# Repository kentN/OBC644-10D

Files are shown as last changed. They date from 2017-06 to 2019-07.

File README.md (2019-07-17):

# OBC644-10D
ATmega644/1284-based arduino compatible on-board computer Reference Model

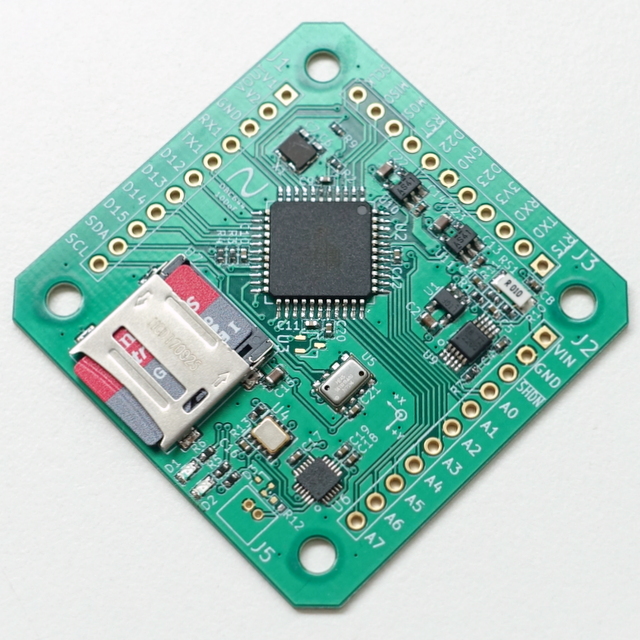
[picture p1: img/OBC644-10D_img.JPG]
PCB_img OBC644-10D

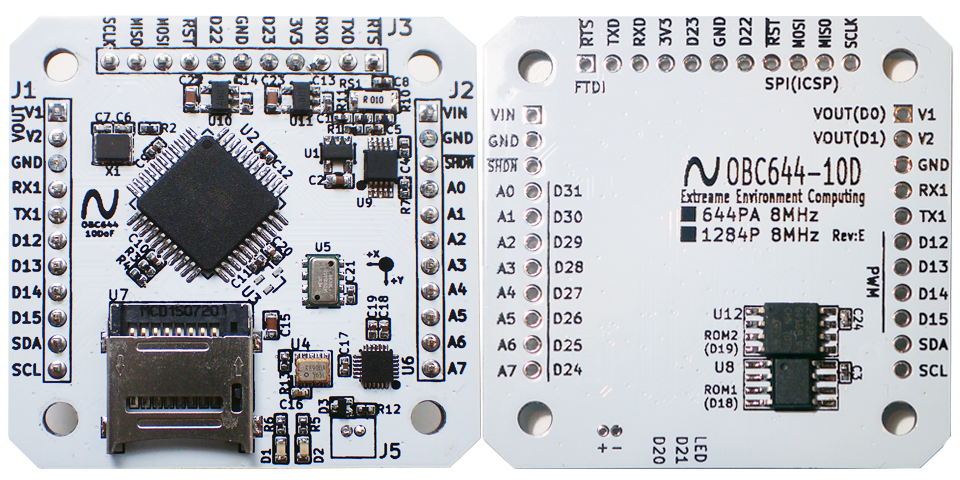
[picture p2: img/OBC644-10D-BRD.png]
PCB_3D


----------

## Features ##
- 3.3V system / LVTTL Logic level
- Two user Power Output with ON-OFF Control
- ATmega644P or ATmega1284P, 8MHz
- Size: 45x45mm  pin pitch compatible with UP-204GSR Universal PCB
- microSD hinge socket
- Two SPI ROM Option (FlashROM, FRAM, etc..) support SO8W and SO8N
- MPU-9250 9Dof Sensor
- MS5611  Baromater
- RX8900 RealTime Clock (TCXO) (Backup Battery Option)
- INA226 Current Shunt monitor
- I2C x1, UART x2, SPIx1, UserADCch x8, GPIOx14  

----------

## System Block ##
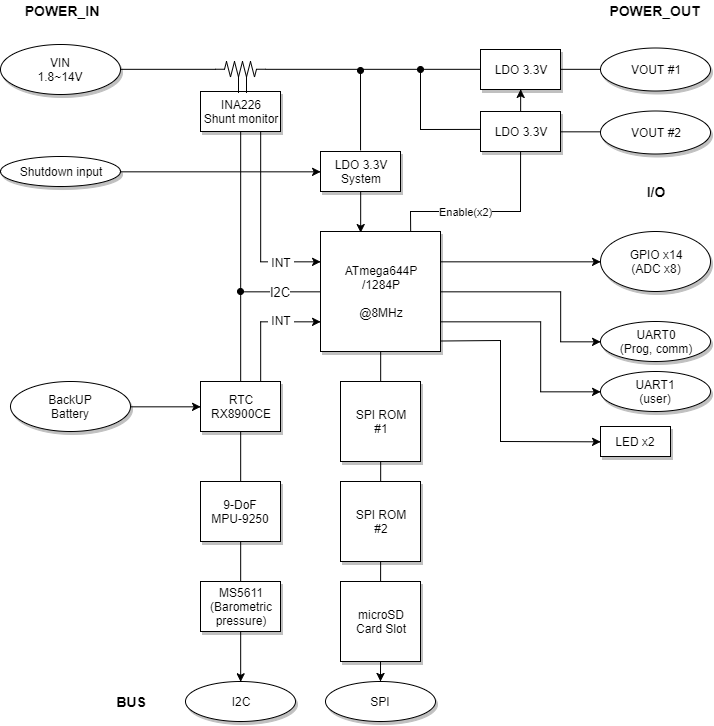
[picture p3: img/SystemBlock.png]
system_diagram


## PIN Map ##
- VIN has Reverse current protection

----------

## Applications ##

- analog & Motion Datalogger
- Energy Harvest sensor
- DIY Space
- DIY HAB

----------

## Project Environment ##

- KiCad (4.0.x)
- Arduino IDE (1.8.X)
- Sanguino bootloader ( https://github.com/Lauszus/Sanguino )
- SDfatlib 

## Project Status ##

- end of life (EOL)

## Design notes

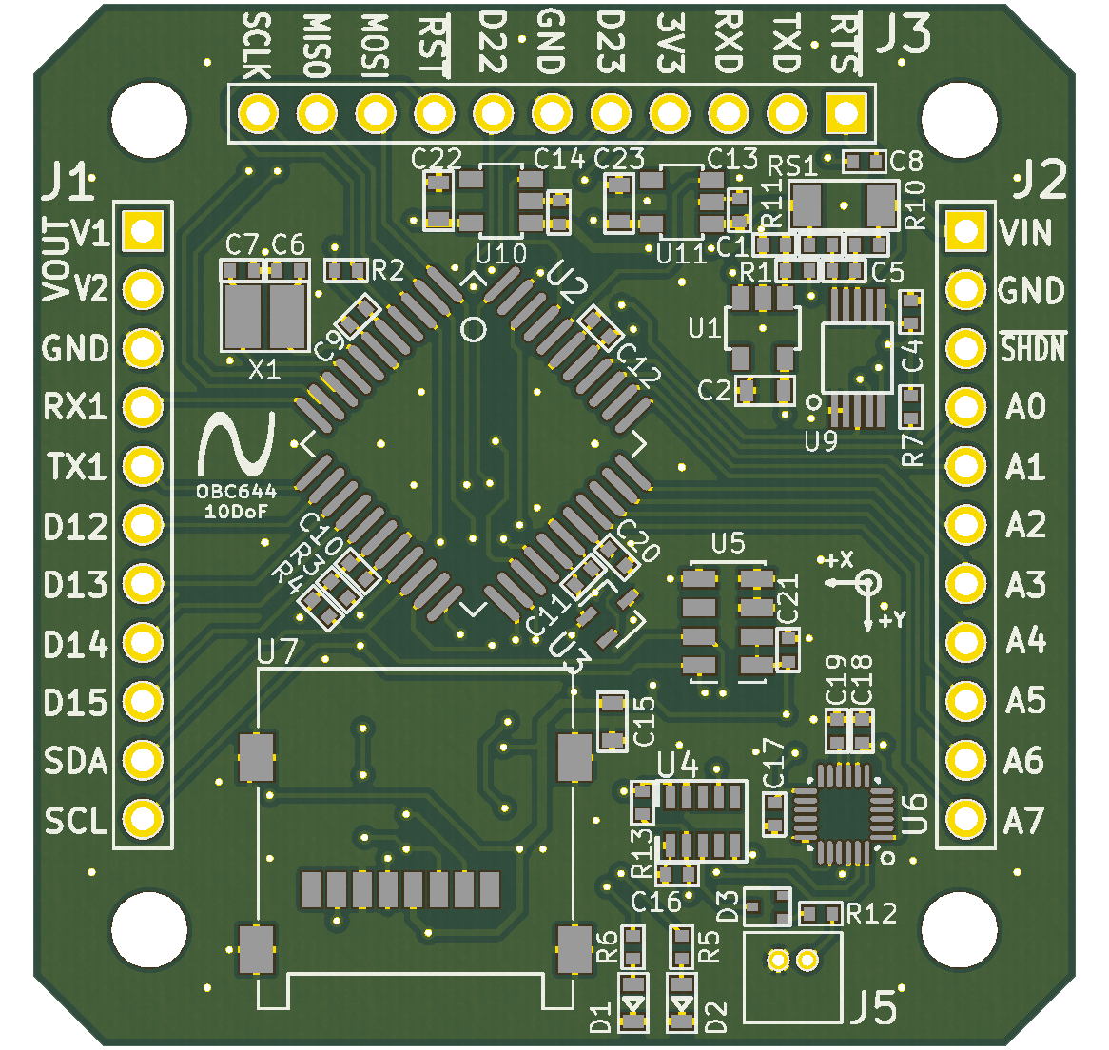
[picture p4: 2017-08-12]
img/OBC644-10D_F.png

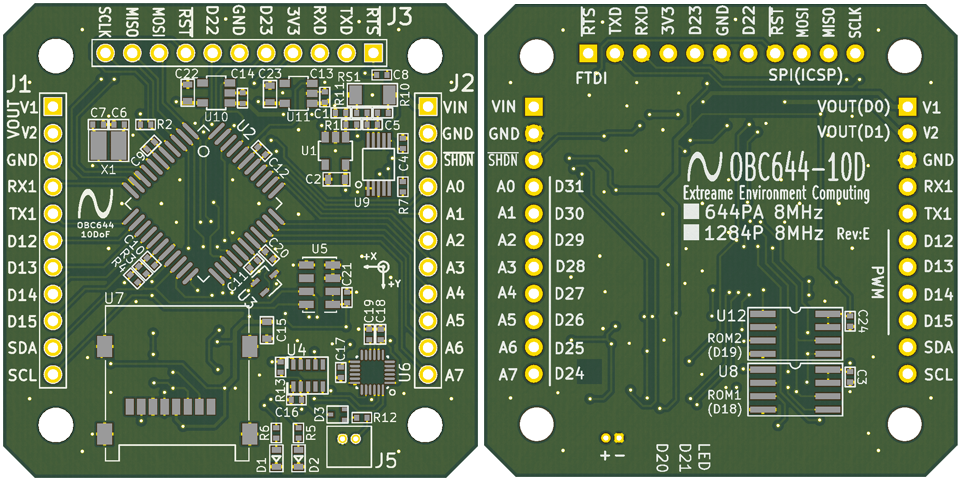
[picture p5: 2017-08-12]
img/OBC644-10D_PCB.png

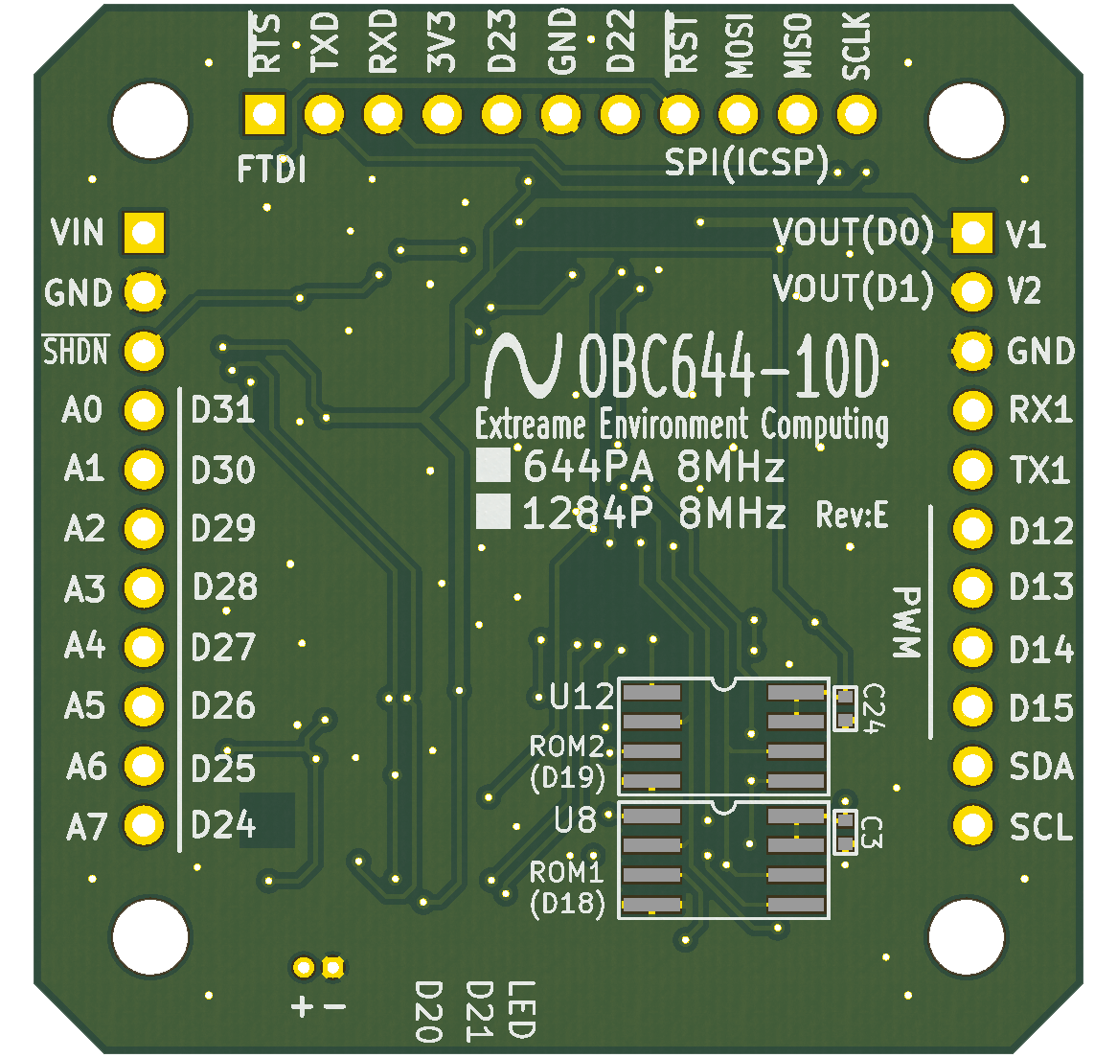
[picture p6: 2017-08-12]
img/OBC644-10D_B.png

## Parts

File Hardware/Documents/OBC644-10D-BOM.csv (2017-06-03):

Reference | Value | Footprint | Datasheet
X1 | NX3225GD-8MHZ | CRYSTAL:3225-2
C1 | 1u | EIA:0402
C10 | 0.1u | EIA:0402
C11 | 0.1u | EIA:0402
C12 | 0.1u | EIA:0402
C13 | 1u | EIA:0402
C14 | 1u | EIA:0402
C15 | 10u | EIA:0603
C16 | 0.1u | EIA:0402
C17 | 0.01u | EIA:0402
C18 | 0.1u | EIA:0402
C19 | 0.1u | EIA:0402
C2 | 10u | EIA:0603
C20 | 0.1u | EIA:0402
C21 | 0.1u | EIA:0402
C22 | 10u | EIA:0603
C23 | 10u | EIA:0603
C24 | 0.1u | EIA:0402
C3 | 0.1u | EIA:0402
C4 | 1u | EIA:0402
C5 | 0.1u | EIA:0402
C6 | 15p | EIA:0402
C7 | 15p | EIA:0402
C8 | 0.1u | EIA:0402
C9 | 0.1u | EIA:0402
D1 | SML-D12M8WT86 | DIODE:0603
D2 | SML-D12M8WT86 | DIODE:0603
D3 | BAS70T-05T-7-F | DIODE:SOT523HY
J1 | CONN_11 | CONN_2.54MM:1x11P
J2 | CONN_11 | CONN_2.54MM:1x11P
J3 | CONN_4 | CONN_2.54MM:1x4P
J4 | CONN_6 | CONN_2.54MM:1x6DP
J5 | 53047 | CONN_1.27MM:53047
R1 | 10k | EIA:0402
R10 | 4.7 | EIA:0402
R11 | 4.7 | EIA:0402
R12 | 1k | EIA:0402
R13 | 10k | EIA:0402
R2 | 10k | EIA:0402
R3 | 3.3k | EIA:0402
R4 | 3.3k | EIA:0402
R5 | 1k | EIA:0402
R6 | 1k | EIA:0402
R7 | 10k | EIA:0402
RS1 | 0.01 | EIA:1206
U1 | LT1761ES5-3.3 | TI:SOT-25
U10 | LT1761ES5-xx | TI:SOT-25
U11 | LT1761ES5-xx | TI:SOT-25
U12 | M25XX_ROM2 | TI:SO8
U2 | ATMEGA644PA-AUR | QFP_QFN:TQFP_44
U3 | REF3320AIDCKT | TI:SC-70
U4 | RX8900CE | CRYSTAL:RX8900CE
U5 | MS561101BA03-00 | LGA:8_MS
U6 | MPU-9250 | QFP_QFN:QFN24
U7 | microSD_hinge 0472192001 | SOCKET:microSD_hinge
U8 | M25XX_ROM1 | TI:SO8
U9 | INA226AQDGSRQ1 | TI:MSOP10

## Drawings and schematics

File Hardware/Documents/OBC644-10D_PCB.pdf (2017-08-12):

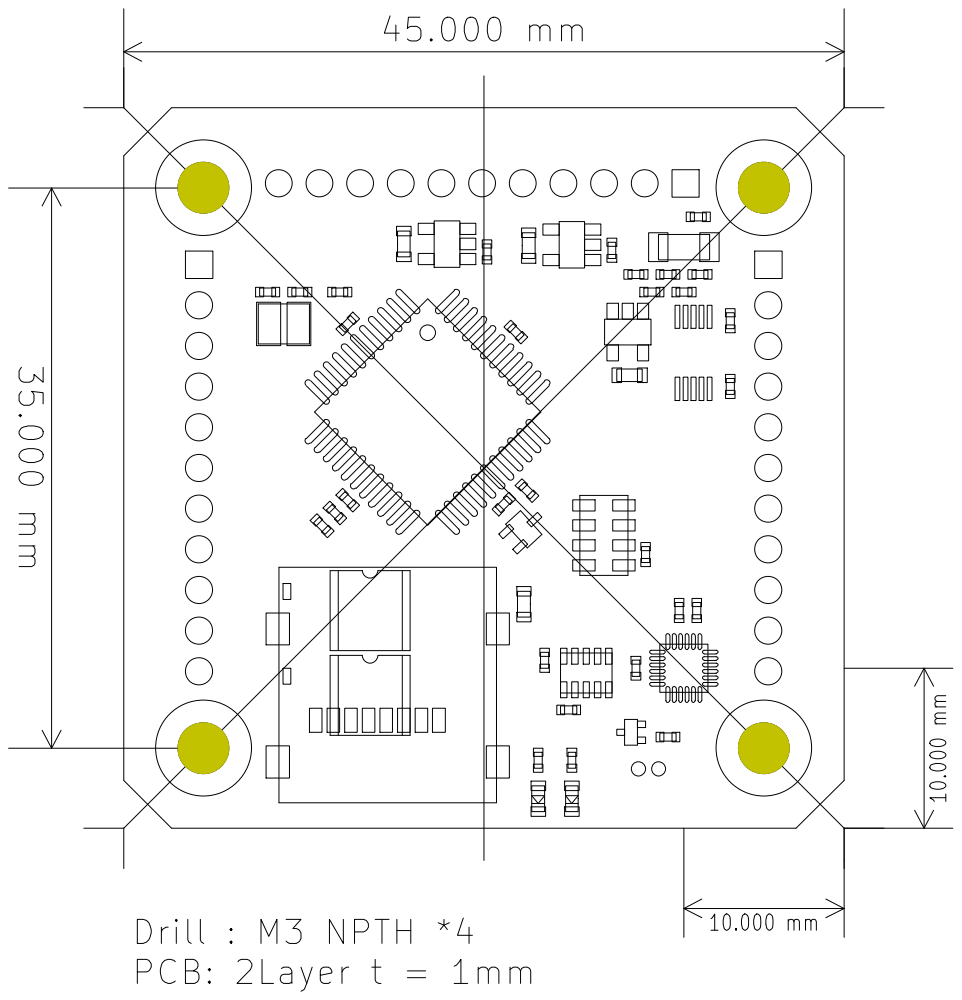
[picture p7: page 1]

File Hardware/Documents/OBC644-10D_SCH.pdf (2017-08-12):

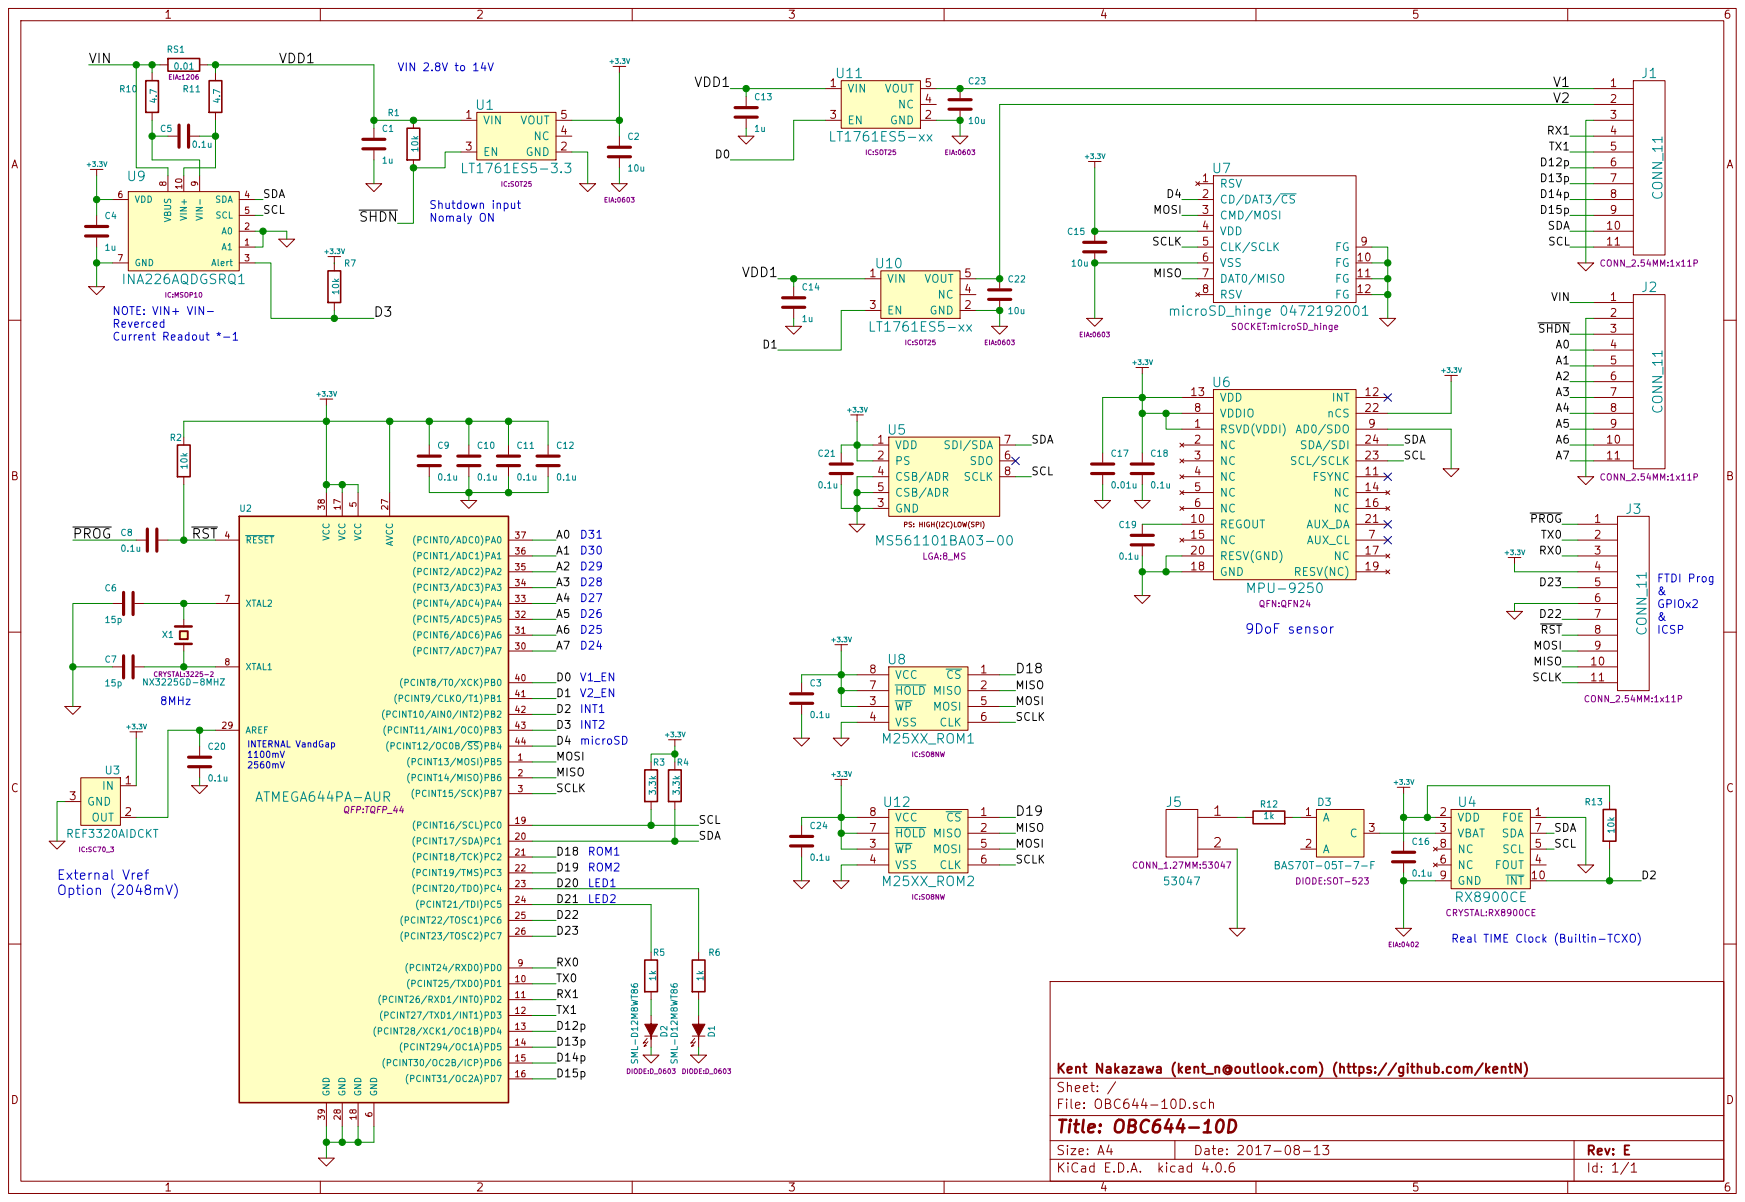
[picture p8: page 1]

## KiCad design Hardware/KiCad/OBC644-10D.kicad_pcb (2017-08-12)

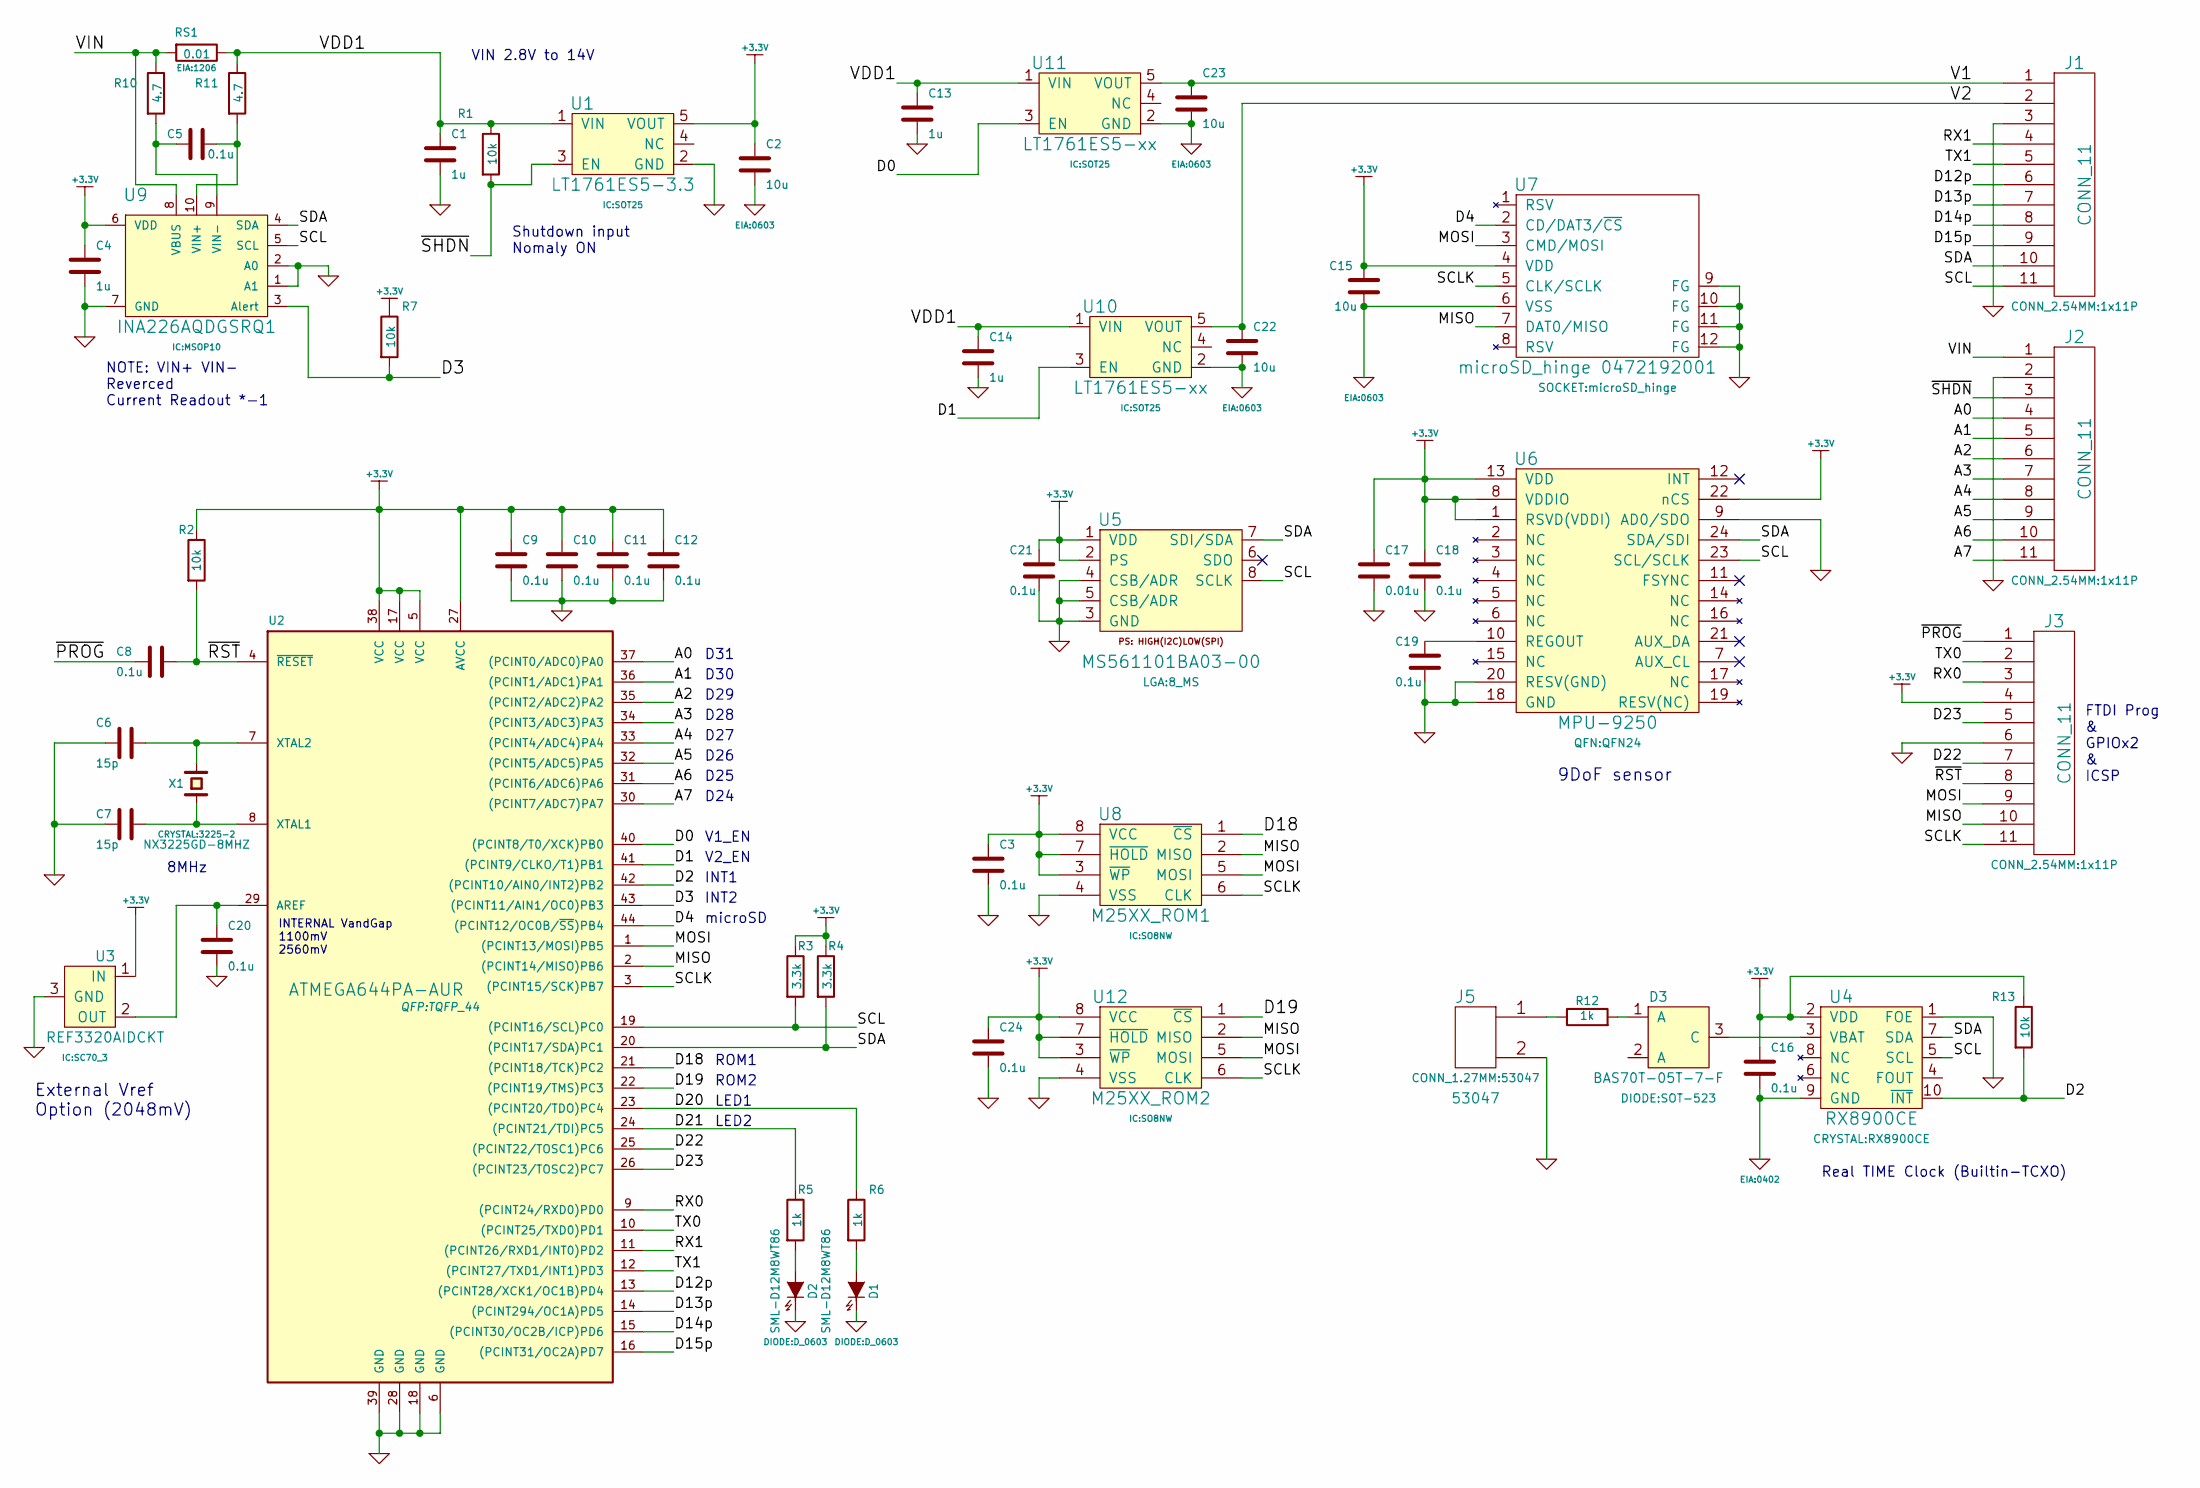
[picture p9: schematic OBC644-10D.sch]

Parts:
C1, C4, C13, C14: 1u; 0402
C2, C15, C22, C23: 10u; 0603
C3, C5, C8, C9, C10, C11, C12, C16, C18, C19, C20, C21, C24: 0.1u; 0402
C6, C7: 15p; 0402
C17: 0.01u; 0402
D1, D2: SML-D12M8WT86; D_0603
D3: BAS70T-05T-7-F; SOT-523
J1, J2, J3: CONN_11; 1x11P
J5: 53047
R1, R2, R7, R13: 10k; 0402
R3, R4: 3.3k; 0402
R5, R6, R12: 1k; 0402
R10, R11: 4.7; 0402
RS1: 0.01; 1206
U1: LT1761ES5-3.3; SOT25
U2: ATMEGA644PA-AUR; TQFP_44
U3: REF3320AIDCKT; SC70_3
U4: RX8900CE
U5: MS561101BA03-00; 8_MS
U6: MPU-9250; QFN24
U7: microSD_hinge 0472192001; microSD_hinge
U8: M25XX_ROM1; SO8NW
U9: INA226AQDGSRQ1; MSOP10
U10, U11: LT1761ES5-xx; SOT25
U12: M25XX_ROM2; SO8NW
X1: NX3225GD-8MHZ; 3225-2

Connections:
+3.3V: C2.1, C3.1, C4.1, C9.1, C10.1, C11.1, C12.1, C15.1, C16.1, C17.1, C18.1, C21.1, C24.1, J3.4, R2.1, R3.1, R4.1, R7.1, R13.1, U1.5 (VOUT), U2.5 (VCC), U2.17 (VCC), U2.27 (AVCC), U2.38 (VCC), U3.1 (IN), U4.2 (VDD), U5.1 (VDD), U5.2 (PS), U6.1 (RSVD(VDDI)), U6.8 (VDDIO), U6.13 (VDD), U6.22 (nCS), U7.4 (VDD), U8.3 (~WP~), U8.7 (~HOLD~), U8.8 (VCC), U9.6 (VDD), U12.3 (~WP~), U12.7 (~HOLD~), U12.8 (VCC)
/A0: J2.4, U2.37 ((PCINT0/ADC0)PA0)
/A1: J2.5, U2.36 ((PCINT1/ADC1)PA1)
/A2: J2.6, U2.35 ((PCINT2/ADC2)PA2)
/A3: J2.7, U2.34 ((PCINT3/ADC3)PA3)
/A4: J2.8, U2.33 ((PCINT4/ADC4)PA4)
/A5: J2.9, U2.32 ((PCINT5/ADC5)PA5)
/A6: J2.10, U2.31 ((PCINT6/ADC6)PA6)
/A7: J2.11, U2.30 ((PCINT7/ADC7)PA7)
/D0: U2.40 ((PCINT8/T0/XCK)PB0), U11.3 (EN)
/D1: U2.41 ((PCINT9/CLKO/T1)PB1), U10.3 (EN)
/D2: R13.2, U2.42 ((PCINT10/AIN0/INT2)PB2), U4.10 (~INT)
/D3: R7.2, U2.43 ((PCINT11/AIN1/OC0)PB3), U9.3 (Alert)
/D4: U2.44 ((PCINT12/OC0B/~SS~)PB4), U7.2 (CD/DAT3/~CS~)
/D12p: J1.6, U2.13 ((PCINT28/XCK1/OC1B)PD4)
/D13p: J1.7, U2.14 ((PCINT294/OC1A)PD5)
/D14p: J1.8, U2.15 ((PCINT30/OC2B/ICP)PD6)
/D15p: J1.9, U2.16 ((PCINT31/OC2A)PD7)
/D18: U2.21 ((PCINT18/TCK)PC2), U8.1 (~CS~)
/D19: U2.22 ((PCINT19/TMS)PC3), U12.1 (~CS~)
/D20: R6.1, U2.23 ((PCINT20/TDO)PC4)
/D21: R5.1, U2.24 ((PCINT21/TDI)PC5)
/D22: J3.7, U2.25 ((PCINT22/TOSC1)PC6)
/D23: J3.5, U2.26 ((PCINT23/TOSC2)PC7)
/MISO: J3.10, U2.2 ((PCINT14/MISO)PB6), U7.7 (DAT0/MISO), U8.2 (MISO), U12.2 (MISO)
/MOSI: J3.9, U2.1 ((PCINT13/MOSI)PB5), U7.3 (CMD/MOSI), U8.5 (MOSI), U12.5 (MOSI)
/RX0: J3.3, U2.9 ((PCINT24/RXD0)PD0)
/RX1: J1.4, U2.11 ((PCINT26/RXD1/INT0)PD2)
/SCL: J1.11, R3.2, U2.19 ((PCINT16/SCL)PC0), U4.5 (SCL), U5.8 (SCLK), U6.23 (SCL/SCLK), U9.5 (SCL)
/SCLK: J3.11, U2.3 ((PCINT15/SCK)PB7), U7.5 (CLK/SCLK), U8.6 (CLK), U12.6 (CLK)
/SDA: J1.10, R4.2, U2.20 ((PCINT17/SDA)PC1), U4.7 (SDA), U5.7 (SDI/SDA), U6.24 (SDA/SDI), U9.4 (SDA)
/TX0: J3.2, U2.10 ((PCINT25/TXD0)PD1)
/TX1: J1.5, U2.12 ((PCINT27/TXD1/INT1)PD3)
/V1: C23.1, J1.1, U11.5 (VOUT)
/V2: C22.1, J1.2, U10.5 (VOUT)
/VDD1: C1.1, C13.1, C14.1, R1.1, R11.1, RS1.1, U1.1 (VIN), U10.1 (VIN), U11.1 (VIN)
/VIN: J2.1, R10.1, RS1.2, U9.8 (VBUS)
/~PROG: C8.2, J3.1
/~RST: C8.1, J3.8, R2.2, U2.4 (~RESET)
/~SHDN: J2.3, R1.2, U1.3 (EN)
GND: C1.2, C2.2, C3.2, C4.2, C6.2, C7.2, C9.2, C10.2, C11.2, C12.2, C13.2, C14.2, C15.2, C16.2, C17.2, C18.2, C19.2, C20.2, C21.2, C22.2, C23.2, C24.2, D1.2 (K), D2.2 (K), J1.3, J2.2, J3.6, J5.2 (PM), U1.2 (GND), U2.6 (GND), U2.18 (GND), U2.28 (GND), U2.39 (GND), U3.3 (GND), U4.1 (FOE), U4.9 (GND), U5.3 (GND), U5.4 (CSB/ADR), U5.5 (CSB/ADR), U6.9 (AD0/SDO), U6.18 (GND), U6.20 (RESV(GND)), U7.6 (VSS), U7.9 (FG), U7.10 (FG), U7.11 (FG), U7.12 (FG), U8.4 (VSS), U9.1 (A1), U9.2 (A0), U9.7 (GND), U10.2 (GND), U11.2 (GND), U12.4 (VSS)
unnamed: C5.1, R11.2, U9.10 (VIN+)
unnamed: C5.2, R10.2, U9.9 (VIN-)
unnamed: C6.1, U2.7 (XTAL2), X1.2
unnamed: C7.1, U2.8 (XTAL1), X1.1
unnamed: C19.1, U6.10 (REGOUT)
unnamed: C20.1, U2.29 (AREF), U3.2 (OUT)
unnamed: D1.1 (A), R6.2
unnamed: D2.1 (A), R5.2
unnamed: D3.1 (A), R12.2
unnamed: D3.3 (C), U4.3 (VBAT)
unnamed: J5.1, R12.1

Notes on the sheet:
8MHz
Shutdown input Nomaly ON
VIN 2.8V to 14V
Real TIME Clock (Builtin-TCXO)
9DoF sensor
External Vref Option (2048mV)
INTERNAL VandGap 1100mV 2560mV
ROM1
ROM2
LED2
LED1
INT1
INT2
microSD
V1_EN
V2_EN
D31
D30
D29
D28
D27
D26
D25
D24
NOTE: VIN+ VIN- Reverced Current Readout *-1
FTDI Prog & GPIOx2 & ICSP

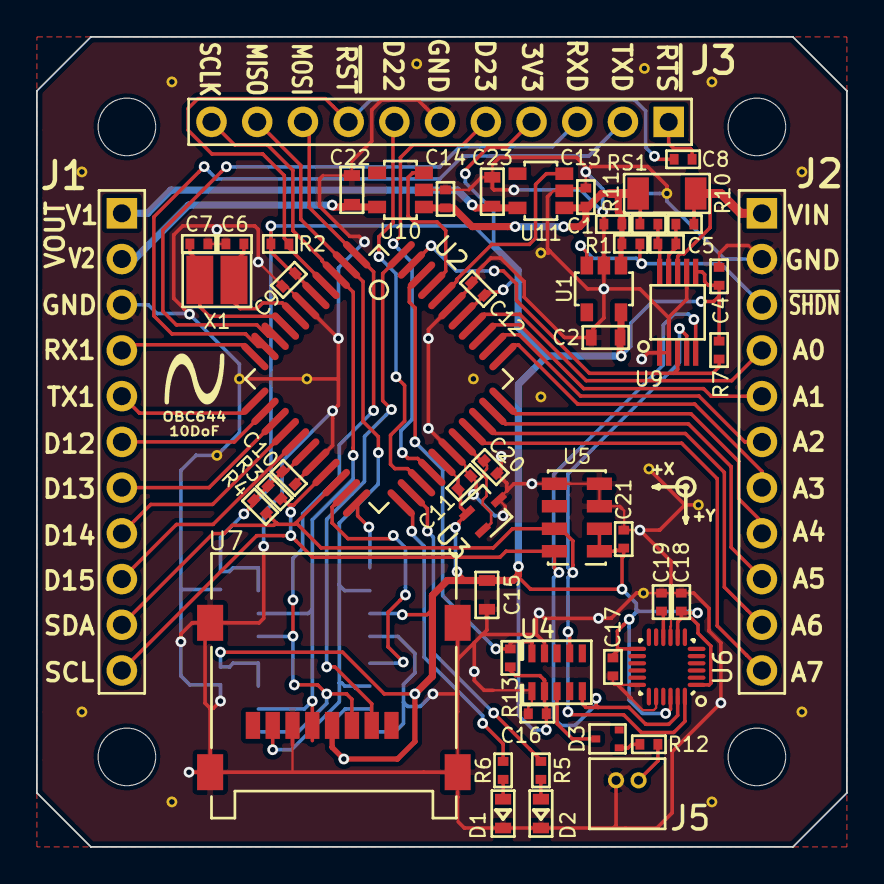
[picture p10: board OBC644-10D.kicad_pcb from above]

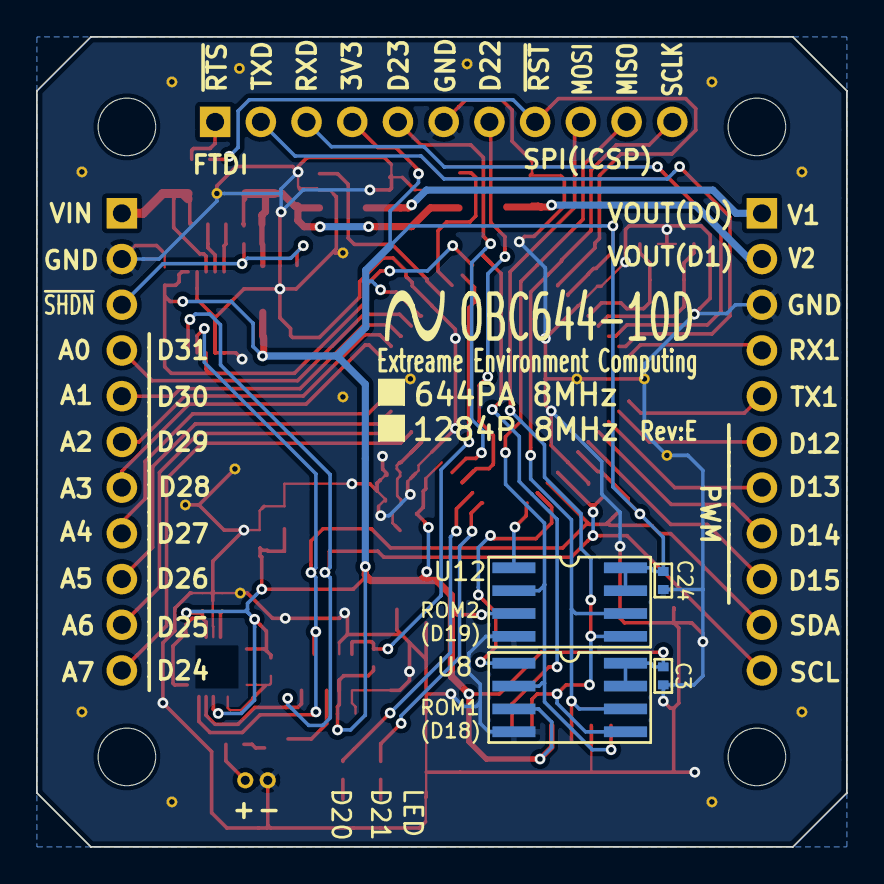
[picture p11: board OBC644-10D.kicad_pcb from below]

Board: 2 copper layers, 45.0 x 45.0 mm, 60 parts (4 on the bottom side), 52 nets.

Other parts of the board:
Drill_M3, Drill_M3#2, Drill_M3#3, Drill_M3#4: H**; drill_M3

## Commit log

2017-05-18 update HW files
    [OBC644-10D-BOM.csv, OBC644-10D.kicad_pcb, OBC644-10D.sch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]
2017-05-22 fix spacing
    [OBC644-10D.kicad_pcb]
2017-06-03 Fix PCB and schematic
    fix ShuntResistor size & routing
    change R5,R6 value
    [OBC644-10D-BOM.csv, OBC644-10D.kicad_pcb, OBC644-10D.sch]
2017-06-04 Add VCPU OUTPUT
    add system voltage output PIN (J6)
2017-06-04 Add VCPU OUTPUT
    [OBC644-10D.kicad_pcb, OBC644-10D.sch]
2017-08-12 Update Rev:E
    Add some Pins (3V3, UART_GPIO)
    Change SO8-ROM Footprints
    [OBC644-10D.kicad_pcb, OBC644-10D.sch]
2017-08-27 update PCB image(rev:E)
